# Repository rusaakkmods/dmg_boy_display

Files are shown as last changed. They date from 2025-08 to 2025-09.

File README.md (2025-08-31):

# DMG Boy Display: Real-Time Game Boy LCD Capture System

📋 **[Complete PCB Schematics & BOM Available](schematics/)**

A high-performance Game Boy LCD capture and display system for the Raspberry Pi Pico, supporting multiple TFT display types with hardware-accelerated PIO capture and DMA-optimized rendering.

## 📸 Preview Gallery

| ST7789 (240x240) | ILI9341 (240x320) | ILI9342 (240x320) | ST7796 (320x480) | SH1107 OLED (128x128) |
|:---:|:---:|:---:|:---:|:---:|
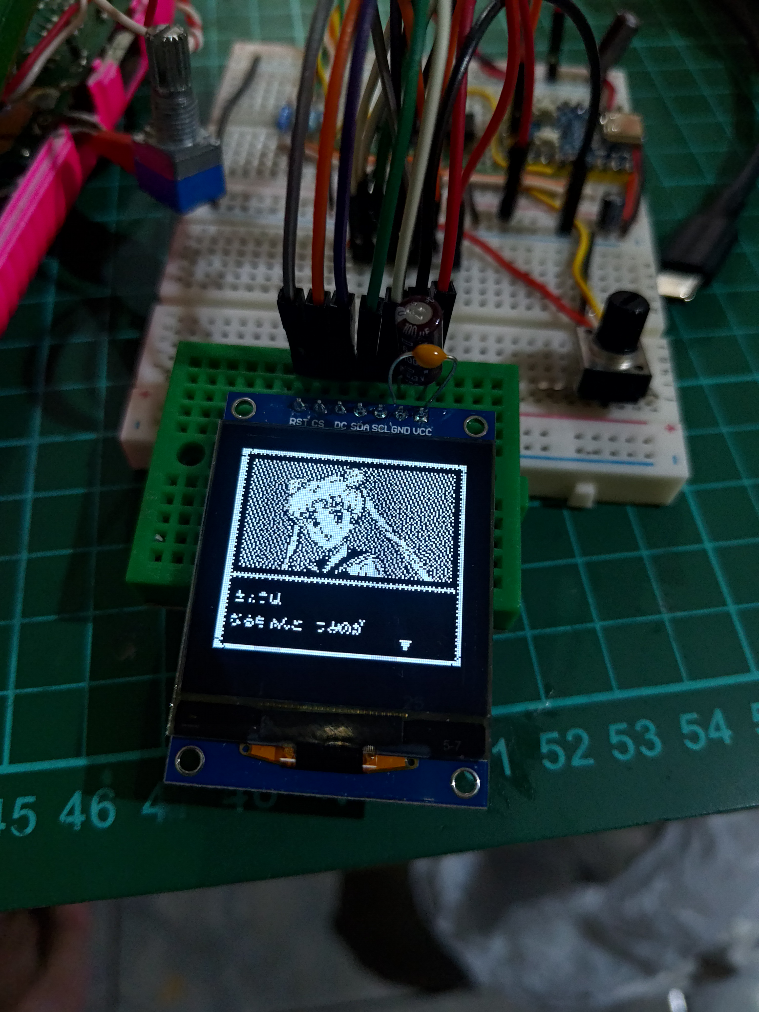
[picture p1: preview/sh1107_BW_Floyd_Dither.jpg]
SH1107
| ST7789 | ILI9341 | ILI9342 | ST7796 |  |
| 1.5x Scaling, Centered | 1.5x Scaling, Top Aligned | 1.5x Scaling, Top Aligned | 2x Scaling, Top Aligned | Floyd-Steinberg Dither, B&W |

| RP2040-Zero Compact | SH1107 OLED Video Demo |
|:---:|:---:|
| RP2040-Zero | SH1107 Video |
| Compact 60% Smaller Build | Monochrome OLED in Action |

📁 **More photos and videos, including new preview images, are available in the [preview/](preview/) folder**

## 📱 Follow My Projects

**🔥 Follow [@rusaakkmods](https://www.instagram.com/rusaakkmods/) on Instagram for more retro gaming mods and electronics projects!**

👍 **Like and follow for:**
- Behind-the-scenes development
- New project updates  
- Retro gaming modifications
- Electronics tutorials

## 🎮 What It Does

This project captures the LCD data from a Game Boy (DMG) in real-time and displays it on modern TFT screens with the following features:

- **Real-Time Capture**: Uses RP2040's PIO (Programmable I/O) for hardware-timed Game Boy LCD signal capture
- **Multi-Display Support**: ST7789, ILI9341, ILI9342, ST7796, and SH1107 OLED displays with optimized drivers
- **Intelligent Scaling**: Automatic resolution scaling with display-specific optimizations
- **Advanced Dithering**: Floyd-Steinberg and Bayer dithering algorithms for monochrome displays
- **DMA Acceleration**: Hardware DMA for fast image transfers and smooth frame rates
- **Color Mapping**: Authentic Game Boy green color palettes for each display type
- **Zero Lag**: Hardware-level capture with minimal latency

## 🖥️ Supported Displays

### ST7789 (240x240)
- **SPI Speed**: 40MHz
- **Scaling**: 1.5x (160x144 → 240x216)
- **Position**: Vertically centered
- **Colors**: Classic Game Boy green tones

### ILI9341 (240x320)
- **SPI Speed**: 40MHz
- **Scaling**: 1.5x (160x144 → 240x216)
- **Position**: Top aligned
- **Colors**: Optimized green palette

### ILI9342 (240x320) *(New!)*
- **SPI Speed**: 40MHz
- **Scaling**: 1.5x (160x144 → 240x216)
- **Position**: Top aligned
- **Colors**: Optimized green palette
- **Notes**: Drop-in replacement for ILI9341 with improved compatibility

### ST7796 (320x480)
- **SPI Speed**: 62.5MHz
- **Scaling**: 2x (160x144 → 320x288)
- **Position**: Top aligned
- **Features**: Enhanced performance optimizations

### SH1107 OLED (128x128) *(New!)*
- **SPI Speed**: 8MHz
- **Resolution**: 128x128 monochrome OLED
- **Scaling**: 0.8x (160x144 → 128x115)
- **Position**: Centered
- **Dithering**: Floyd-Steinberg or Bayer dithering for black & white conversion
- **Features**: Ultra-low power consumption, high contrast ratio

## 🎨 Advanced Dithering Algorithms

### Floyd-Steinberg Dithering *(New!)*
High-quality error diffusion dithering algorithm that provides superior image quality for monochrome displays:
- **Better Quality**: Superior visual results compared to ordered dithering
- **Error Diffusion**: Distributes quantization errors to neighboring pixels
- **Ideal for**: Static images and high-quality monochrome conversion
- **Usage**: Automatically enabled for SH1107 OLED displays

### Bayer Ordered Dithering
Fast, efficient ordered dithering using an 8x8 Bayer matrix:
- **High Performance**: Minimal CPU overhead, perfect for real-time applications
- **Consistent Pattern**: Stable, repeatable dithering pattern
- **Real-time Friendly**: Optimized for continuous Game Boy capture
- **Fallback Option**: Alternative to Floyd-Steinberg when performance is critical

### Black & White (Monochrome) Feature for OLED/Monochrome Displays
For future OLED and other monochrome (1-bit) display support, a new black-and-white mode is available. This mode uses a simple, fast 8x8 Bayer ordered dithering algorithm (instead of the more CPU-intensive Floyd-Steinberg method) to simulate grayscale on black-and-white screens. This approach is chosen for its efficiency and suitability for microcontrollers, making it ideal for OLED and similar displays. Enable this in the display configuration for best results on monochrome hardware.

> **Note:** The Bayer dither is much less CPU-intensive than Floyd-Steinberg, making it a better fit for real-time applications on the RP2040.

## 🔧 Hardware Requirements

### Raspberry Pi Pico
- RP2040 microcontroller
- Standard Pico board or Pico W

### PCB & Components
📋 **[Complete schematics, PCB design, and BOM](schematics/)** available in KiCad format
- Custom PCB recommended for reliable connections
- Through-hole components for easy assembly
- All parts available from common distributors

### Game Boy Connection (DMG-01 Flex Cable)
| Signal | GameBoy LCD Connector | Pico Pin | Description |
|---|---|---|---|
| GND | Pin 21 | GND | Ground |
| Pixel Clock | Pin 14 | GP2 | LCD pixel clock signal |
| Data 0 | Pin 15 | GP3 | LCD data bit 0 |
| Data 1 | Pin 16 | GP4 | LCD data bit 1 |
| Vertical Sync | Pin 12 | GP5 | LCD vertical sync signal |
| Regulated +5V | Pin 11 | VSYS | Power Supply |

### Display Connection (SPI)
| Signal | Pico Pin | Description |
|---|---|---|
| MOSI | GPIO 11  | SPI Data Output |
| SCK | GPIO 10  | SPI Clock |
| CS | GPIO 9 | Chip Select |
| DC | GPIO 12  | Data/Command |
| RESET  | GPIO 13  | Display Reset |
| BL | GPIO 8 | Backlight Control |

## 🚀 Quick Start

### 1. Clone Repository
```bash
git https://github.com/rusaakkmods/dmg_boy_display
cd dmg_boy_display
```

### 2. Configure Display Type
Edit `main.cpp` and uncomment your display type:
```cpp
// Choose display type: uncomment one of these lines
//#define USE_ST7789
//#define USE_ILI9341
//#define USE_ILI9342
//#define USE_ST7796
#define USE_SH1107    // ← Uncomment your display
```

### 3. Build with Ninja (Recommended)
```bash
# Create build directory
mkdir build && cd build

# Configure with Ninja generator (faster builds)
cmake -G Ninja ..

# Build project
ninja

# Flash to Pico
cp dmg_boy_display.uf2 /path/to/pico/drive/
```

### Alternative: Standard Make
```bash
mkdir build && cd build
cmake ..
make -j4
```

## 🏗️ Project Structure

```
├── main.cpp                     # Main application
├── CMakeLists.txt               # Build configuration
├── include/                     # Header files
│   ├── logo.h                  # Logo graphics data
│   ├── dither.hpp              # Dithering algorithms (NEW)
│   ├── scaler.hpp              # Image scaling utilities
│   └── displays/               # Display drivers
│       ├── st7789/            # ST7789 driver
│       ├── ili9341/           # ILI9341 driver
│       ├── ili9342/           # ILI9342 driver
│       ├── ili9488/           # ILI9488 driver (future)
│       ├── sh1107/            # SH1107 OLED driver (NEW)
│       └── st7796/            # ST7796 driver
├── src/                        # Source implementations
│   ├── dither.cpp             # Dithering algorithms (NEW)
│   ├── scaler.cpp             # Image scaling utilities
│   └── displays/              # Driver implementations
│       ├── st7789/            # ST7789 source files
│       ├── ili9341/           # ILI9341 source files
│       ├── ili9342/           # ILI9342 source files
│       ├── ili9488/           # ILI9488 source files
│       ├── sh1107/            # SH1107 OLED source files (NEW)
│       └── st7796/            # ST7796 source files
├── pio/gblcd/                 # PIO programs
│   ├── gblcd.pio             # Game Boy LCD capture
│   └── README.md             # PIO documentation
└── .gitignore                 # Git ignore rules
```

## ⚡ Performance Features

### Hardware Acceleration
- **PIO Capture**: Dedicated state machine for precise Game Boy timing
- **DMA Transfers**: Zero-CPU image copying for smooth frame rates
- **Optimized Scaling**: Pre-computed lookup tables and unrolled loops
- **Advanced Dithering**: Hardware-optimized Floyd-Steinberg and Bayer algorithms

### Display-Specific Optimizations
- **ST7796**: 2x pixel scaling with loop unrolling
- **SH1107 OLED**: Optimized monochrome conversion with dithering
- **Color Lookup**: Pre-computed Game Boy color palettes
- **Buffer Management**: Optimized buffer sizes per display

### Build System
- **Ninja Generator**: Recommended for faster compilation
- **Simplified CMake**: Clean, maintainable build configuration
- **Multi-target**: Single executable with compile-time display selection

## 🔧 Advanced Configuration

### Custom Pin Mapping
Modify pin assignments in `main.cpp`:
```cpp
config.pin_din = 11;    // MOSI
config.pin_sck = 10;    // SCK
config.pin_cs = 9;      // CS
config.pin_dc = 12;     // DC
config.pin_reset = 13;  // RESET
config.pin_bl = 8;      // Backlight
```

### SPI Speed Tuning
Adjust SPI frequencies for your setup:
```cpp
// Conservative (stable)
config.spi_speed_hz = 25 * 1000 * 1000;  // 25MHz

// Aggressive (maximum performance)
config.spi_speed_hz = 62.5 * 1000 * 1000;  // 62.5MHz
```

### DMA Buffer Optimization
Tune buffer sizes for performance:
```cpp
config.dma.buffer_size = 4096;  // Larger = smoother, more RAM
```

### Dithering Algorithm Selection
Choose between dithering algorithms for monochrome displays:
```cpp
// High quality Floyd-Steinberg (slower, better quality)
floyd_steinberg_dither(buffer, width, height, palette, white, black);

// Fast Bayer ordered dithering (faster, good quality)
fast_bayer_dither(buffer, width, height, palette, white, black);
```

## 🐛 Troubleshooting

### Build Issues
```bash
# Clean build
rm -rf build/
mkdir build && cd build
cmake -G Ninja ..
ninja
```

### Display Problems
1. **No Image**: Check SPI connections and power
2. **Wrong Colors**: Verify display type in `main.cpp`
3. **Slow Frame Rate**: Increase SPI speed or enable DMA

### Game Boy Capture Issues
1. **No Signal**: Verify Game Boy LCD connections
2. **Corrupted Image**: Check PIO timing configuration
3. **Sync Problems**: Ensure proper VSync connection

## 📚 Technical Details

### Game Boy LCD Timing
- **Resolution**: 160x144 pixels
- **Refresh Rate**: ~59.7 Hz
- **Color Depth**: 2-bit (4 shades of green)

### Scaling Algorithms
- **1.5x Scaling**: 160→240, 144→216 (ST7789/ILI9341)
- **2x Scaling**: 160→320, 144→288 (ST7796)
- **Nearest Neighbor**: Preserves pixel art aesthetic

### Memory Usage
- **Source Buffer**: 46KB (160x144x2 bytes)
- **Scaled Buffer**: 101KB-180KB (depending on display)
- **SH1107 Buffer**: 2KB (128x128÷8 bytes for monochrome)
- **Dithering Buffer**: 32KB temporary space for Floyd-Steinberg
- **Total RAM**: ~230KB (fits comfortably in RP2040's 264KB)

## 🛠️ Development

### Adding New Displays
1. Create driver files in `include/displays/newdisplay/`
2. Implement source files in `src/displays/newdisplay/`
3. Add display type to `main.cpp`
4. Update `CMakeLists.txt`

### Performance Profiling
Use Pico's built-in profiling:
```cpp
#include "pico/time.h"
absolute_time_t start = get_absolute_time();
// ... your code ...
int64_t elapsed = absolute_time_diff_us(start, get_absolute_time());
```

## 📄 License

This project is open source. See individual files for license information.

## 🤝 Contributing

1. Fork the repository
2. Create a feature branch
3. Test thoroughly on hardware
4. Submit a pull request

## 🙏 Credits

- Thanks to What's Ken Making Youtube Channel, finally I can finish my project. 
  Please follow his Youtube Channel: https://www.youtube.com/@whatskenmaking
- To my kooky AI Claude 4 for assisting me with code optimization, also for it's artificial apologize :D

## 📱 Connect With Me

**Follow [@rusaakkmods](https://www.instagram.com/rusaakkmods/) on Instagram!**

🔥 **Like, follow, and stay updated with:**
- New electronics projects
- Retro gaming modifications  
- Development progress
- Hardware tutorials
- Behind-the-scenes content

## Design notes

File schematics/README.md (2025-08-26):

# DMG Boy Display - Schematic & P### TFT Display Connection (LCD?)
The SPI TFT display connects directly to Raspberry Pi Pico pins:
| Signal | Pico GPIO | Description | Voltage Notes |
|---|---|---|---|
| **VCC** | **3V3/5V** | **Power supply** | **⚠️ See power requirements below** |
| GND | GND | Ground | - |
| CS | GP9 | Chip select | 3.3V logic |
| RESET | GP13 | Display reset | 3.3V logic |
| DC | GP12 | Data/command | 3.3V logic |
| MOSI | GP11 | SPI data | 3.3V logic |
| SCK | GP10 | SPI clock | 3.3V logic |
| BL | GP8 | Backlight control | 3.3V logic |
This folder contains the complete KiCad project files for the DMG Boy Display PCB.

## 📋 Schematic Preview

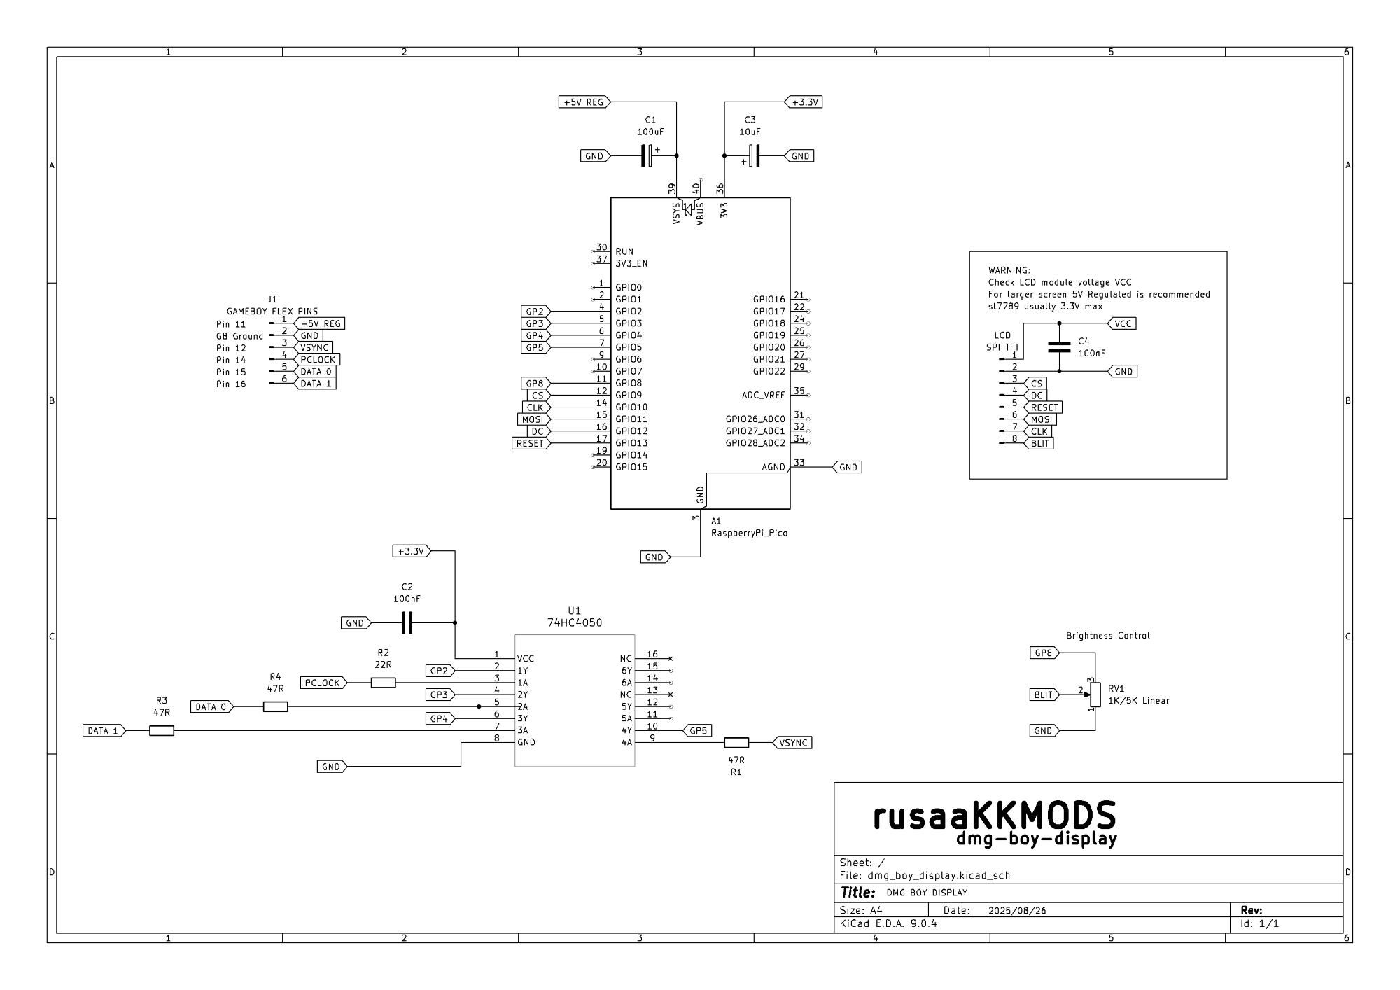
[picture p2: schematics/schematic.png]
Schematic

*Complete schematic showing Game Boy LCD interface and TFT display connections*

## 🛠️ Bill of Materials (BOM)

### Core Components
| Qty | Reference | Value | Package | Description | Datasheet |
|-----|---|---|---|---|---|
| 1 | A1 | RaspberryPi_Pico | THT Module | RP2040 Development Board | [Pico Datasheet](https://datasheets.raspberrypi.com/pico/pico-datasheet.pdf) |
| 1 | U1 | 74HC4050 | N16_TEX | Hex Non-Inverting Buffer | CD74HC4050EG4 |

### Display Interface Components  
| Qty | Reference | Value | Package | Description | Notes |
|-----|---|---|---|---|---|
| 1 | LCD | SPI TFT | Various | TFT Display Module | ST7789/ILI9341/ST7796 |

### Passive Components
| Qty | Reference | Value | Package | Description | Notes |
|-----|---|---|---|---|---|
| 3 | R1,R3,R4 | 47Ω | 0805/THT | Current limiting resistors | Signal conditioning |
| 1 | R2 | 22Ω | 0805/THT | Series resistor | Signal integrity |
| 1 | RV1 | 1K/5K Linear | THT | Potentiometer | Brightness/contrast control |
| 1 | C1 | 100μF | Electrolytic | Power supply capacitor | Bulk decoupling |
| 2 | C2,C4 | 100nF | 0805/THT | Ceramic capacitors | High-freq decoupling |
| 1 | C3 | 10μF | 0805/THT | Tantalum/Ceramic | Power filtering |

### TFT Display Connection (LCD)
The SPI TFT display connects directly to Raspberry Pi Pico pins:
| Signal | Pico GPIO | Description | Voltage Notes |
|---|---|---|---|
| **VCC** | **3V3/5V** | **Power supply** | **⚠️ See power requirements below** |
| GND | GND | Ground | - |
| CS | GP17 | Chip select | 3.3V logic |
| RESET | GP15 | Display reset | 3.3V logic |
| DC | GP20 | Data/command | 3.3V logic |
| MOSI | GP19 | SPI data | 3.3V logic |
| SCK | GP18 | SPI clock | 3.3V logic |
| BL | RV1 Wiper | Backlight control | 3.3V logic |

### ⚠️ Display Power Requirements (VCC)

**IMPORTANT**: Please review your display module's voltage requirements before connecting!

#### Power Options:
1. **3.3V Power (Default/Safe)**
   - Use Pico's 3V3 output
   - ✅ **Safe for all display types**
   - ✅ **ST7789 recommended** (3.3V max)
   - ✅ **Most common configuration**

2. **5V Power (For larger screens)**
   - Use regulated 5V from Game Boy power supply
   - ⚠️ **Check display voltage tolerance first**
   - ✅ **Better for larger displays (3.5"+ screens)**
   - ✅ **Brighter backlight performance**

#### Critical Warnings:
- 🚨 **ST7789 displays**: Usually require **3.3V maximum** - using 5V may damage the display!
- 🚨 **ILI9341 displays**: Check datasheet - some accept 5V, others are 3.3V only
- 🚨 **ST7796 displays**: Most accept 3.3V-5V, but verify your specific module
- 🚨 **Always check your display breakout board specifications**

#### Recommended Approach:
1. **Start with 3.3V** for initial testing (safest option)
2. **Check display performance** - if backlight is too dim for larger screens
3. **Verify 5V compatibility** in your display's datasheet
4. **Only then switch to 5V** if needed and confirmed safe
- **74HC4050 (U1)**: Hex non-inverting buffer for Game Boy signal conditioning
- **RV1 (1K/5K)**: Potentiometer for brightness/contrast adjustment
- **R1,R3,R4 (47Ω)**: Current limiting resistors for signal integrity
- **R2 (22Ω)**: Series resistor for signal conditioning
- **C1 (100μF)**: Bulk power supply decoupling
- **C2,C4 (100nF)**: High-frequency noise filtering
- **C3 (10μF)**: Additional power supply filtering

## 🔍 Design Validation

### Signal Integrity
✅ Proper impedance control for SPI signals  
✅ Adequate ground plane coverage  
✅ Decoupling capacitors near power pins  
✅ Short trace lengths for high-speed signals  

### Power Integrity  
✅ Dedicated power planes  
✅ Power supply filtering  
✅ Current capacity analysis  
✅ Thermal considerations  

## 📧 Support

For questions about the PCB design:
- 📱 Follow [@rusaakkmods](https://www.instagram.com/rusaakkmods/) on Instagram
- 🐛 Open an issue in this repository
- 💬 Discussion in project README

---

**PCB Design by [@rusaakkmods](https://www.instagram.com/rusaakkmods/)**

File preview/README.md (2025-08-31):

# DMG Boy Display - Preview Gallery

This folder contains preview images and videos of the DMG Boy Display project in action with different TFT displays.

## 📸 Preview Images

### ST7789 Display (240x240)
ST7789 Display
*ST7789 240x240 display showing Game Boy content with 1.5x scaling*

### ILI9341 Display (240x320)
ILI9341 Display
*ILI9341 240x320 display showing Game Boy content with 1.5x scaling*

### ILI9342 Display (240x320) *(New!)*
ILI9342 Display
*ILI9342 240x320 display showing Game Boy content with 1.5x scaling*

### ST7796 Display (320x480)
ST7796 Display
*ST7796 320x480 display showing Game Boy content with 2x scaling*

### SH1107 OLED Display (128x128) *(New!)*
SH1107 OLED
*SH1107 128x128 monochrome OLED display with Floyd-Steinberg dithering*

### RP2040-Zero Compact Build
RP2040-Zero Build
*Compact build using Waveshare RP2040-Zero for minimal footprint*

## 🎥 Video Demo
- `preview.mp4` - Video demonstration of the system in action
- `rp2040-Zero_preview.mp4` - RP2040-Zero compact build demonstration
- `sh1107_Monochroe_OLED.mp4` - SH1107 OLED display with real-time dithering *(New!)*

## 📱 Follow for More Projects

**Follow me on Instagram for more retro gaming mods and electronics projects:**

**[@rusaakkmods](https://www.instagram.com/rusaakkmods/)**

🔥 Don't forget to **like** and **follow** for:
- Behind-the-scenes development
- New project updates
- Retro gaming modifications
- Electronics tutorials
- Hardware hacks

## 🛠️ Hardware Specifications

All images show the same Game Boy LCD capture system with different configurations:

### Standard Pico Build
- **Raspberry Pi Pico** (RP2040)
- **Real-time PIO capture** from Game Boy DMG-01
- **Hardware DMA acceleration** for smooth frame rates
- **Authentic Game Boy color palettes**

### Compact RP2040-Zero Build  
- **Waveshare RP2040-Zero** (23.5×18mm)
- **60% smaller** than standard Pico
- **Same performance** and capabilities
- **Ideal for portable/embedded applications**

## 📐 Display Comparisons

| Display  | Resolution | Scaling | Position | Performance | Type |
|---|---|---|---|---|---|
| ST7789 | 240x240 | 1.5x | Centered | 40MHz SPI | TFT Color |
| ILI9341  | 240x320 | 1.5x | Top | 40MHz SPI | TFT Color |
| ILI9342  | 240x320 | 1.5x | Top | 40MHz SPI | TFT Color |
| ST7796 | 320x480 | 2.0x | Top | 62.5MHz SPI | TFT Color |
| SH1107 | 128x128 | 0.8x | Centered | 40MHz SPI | OLED Mono |

## 🎨 Dithering Algorithms *(New!)*

The SH1107 OLED display showcases two advanced dithering algorithms for black & white conversion:

### Floyd-Steinberg Dithering *(Featured in Preview)*
- **High Quality**: Superior visual results with error diffusion
- **Better Detail**: Preserves fine details and gradients
- **Shown in Images**: The preview images demonstrate Floyd-Steinberg quality
- **Best for**: High-quality static conversion and detailed images

### Bayer Ordered Dithering *(Alternative)*
- **High Performance**: Minimal CPU overhead for real-time use
- **Consistent Pattern**: Stable, repeatable results
- **Real-time Friendly**: Optimized for continuous Game Boy capture
- **Best for**: Real-time applications where speed is critical

---

## Black & White (Monochrome) Feature for OLED/Monochrome Displays

A new black-and-white mode is now available for future OLED and other monochrome (1-bit) display support. This mode uses a simple, fast 8x8 Bayer ordered dithering algorithm (instead of the more CPU-intensive Floyd-Steinberg method) to simulate grayscale on black-and-white screens. This approach is chosen for its efficiency and suitability for microcontrollers, making it ideal for OLED and similar displays. Enable this in the display configuration for best results on monochrome hardware.

> **Note:** The Bayer dither is much less CPU-intensive than Floyd-Steinberg, making it a better fit for real-time applications on the RP2040.

---

**Project by [@rusaakkmods](https://www.instagram.com/rusaakkmods/)**

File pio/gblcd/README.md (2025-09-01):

# Game Boy LCD Capture (gblcd.pio)

A high-performance PIO (Programmable I/O) program for capturing Game Boy LCD data using the Raspberry Pi Pico.

## Author

**Ken (What's Ken Making)**
- GitHub: [@whatskenmaking](https://github.com/whatskenmaking)
- YouTube: [What's Ken Making](https://www.youtube.com/@whatskenmaking)
- Master Repository: [Pico-DMG-LCD](https://github.com/whatskenmaking/Pico-DMG-LCD)

## Overview

The `gblcd.pio` is a specialized PIO program designed to capture raw LCD data from the original Game Boy (DMG) hardware in real-time. This library enables the Raspberry Pi Pico to act as a high-speed data capture interface between the Game Boy's LCD controller and external display devices.

## What it Does

The gblcd.pio program captures:
- **Pixel Data**: Raw 2-bit grayscale pixel information from the Game Boy LCD
- **Timing Signals**: VSYNC and pixel clock synchronization
- **Frame Data**: Complete 160x144 pixel frames at 59.7 Hz refresh rate
- **Real-time Processing**: Zero-latency capture suitable for live display output

## How it Works

### PIO Architecture
The program utilizes the RP2040's Programmable I/O (PIO) **Single State Machine** to captures pixel data and VSYNC with precise clock synchronization
   - Waits for clock edges on PIO pin index 0 (GPIO 2 - Game Boy clock)
   - Reads 4 input pins simultaneously using pin indices 0-3 (GPIO 2-5)
   - PIO pin index 0 (GPIO 2): Game Boy clock signal (CPG)
   - PIO pin index 1 (GPIO 3): Pixel data bit 0 (LD0)
   - PIO pin index 2 (GPIO 4): Pixel data bit 1 (LD1)
   - PIO pin index 3 (GPIO 5): VSYNC signal
   - Transfers data to main CPU via FIFO

### Signal Capture Process

```
Game Boy LCD → PIO State Machine → CPU Processing → External Display
```

#### 1. Signal Input
- **CPG (Clock Pulse Generator)**: 4.194304 MHz pixel clock from Game Boy (GPIO 2)
- **LD0-LD1**: 2-bit pixel data lines (grayscale values 0-3) on GPIO 3-4
- **VSYNC**: Vertical sync signal for frame timing (GPIO 5)
- Note: PIO waits on clock (GPIO 2) then captures all signals simultaneously

#### 2. Data Processing
- PIO captures 2-bit pixels at 4.194304 MHz rate
- Each line contains 160 pixels (320 bits of data)
- Frame consists of 144 active lines
- Automatic synchronization with Game Boy timing using VSYNC

#### 3. Memory Management
- CPU polling of PIO FIFO for continuous capture
- 23,040 bytes per frame (160×144×1 byte per pixel)
- Frame synchronization via VSYNC detection
- Direct transfer to display drivers

### Technical Specifications

| Parameter | Value |
|---|---|
| Input Clock | 4.194304 MHz |
| Frame Rate | ~59.7 Hz |
| Resolution | 160×144 pixels |
| Color Depth | 2-bit grayscale (4 shades) |
| Data Rate | ~1.97 MB/s |
| Latency | <1 frame (~16.7ms) |

## Usage

### Hardware Connections
Connect the following Game Boy signals to Raspberry Pi Pico GPIO pins:

```cpp
// Pin assignments - PIO uses pin indices starting from GPIO 2
#define GB_CLK_PIN    2   // Game Boy pixel clock (CPG) - PIO pin index 0
#define GB_DATA0_PIN  3   // Game Boy data bit 0 (LD0) - PIO pin index 1
#define GB_DATA1_PIN  4   // Game Boy data bit 1 (LD1) - PIO pin index 2  
#define GB_VSYNC_PIN  5   // Game Boy vertical sync (VSYNC) - PIO pin index 3

// PIO configuration maps pin indices to GPIO pins:
// sm_config_set_in_pins(&config, 2) sets GPIO 2 as PIO pin index 0
// This automatically assigns GPIO 3,4,5 to PIO pin indices 1,2,3
```

### Software Integration

The PIO program is automatically compiled and included in your project:

```cpp
#include "gblcd.pio.h"

// Initialize PIO program
uint offset = pio_add_program(pio0, &gblcd_program);
gblcd_program_init(pio0, 0, offset, clk_pin, data_pin);
```

## Performance Features

- **Minimal CPU Overhead**: PIO handles timing-critical pixel capture
- **FIFO Integration**: Automatic data transfers without complex buffering
- **Real-time Capture**: Frame-synchronized capture via VSYNC detection
- **Low Latency**: Immediate processing suitable for gaming applications
- **Power Efficient**: Dedicated hardware reduces power consumption

## Applications

This library enables various Game Boy LCD capture applications:
- External display drivers (ST7789, ILI9341, ST7796)
- LCD replacement/upgrade projects
- Game Boy video recording systems
- Real-time streaming solutions
- Emulator development and testing

## Technical Notes

### Timing Requirements
- The PIO program is carefully tuned for Game Boy LCD timing
- Clock edges and data sampling are precisely aligned
- VSYNC detection ensures proper frame synchronization

### Buffer Management
- Implements ping-pong buffering for continuous operation
- Automatic detection of frame boundaries
- Configurable buffer sizes for different display types

### Compatibility
- Designed for original Game Boy (DMG) hardware
- Compatible with Game Boy Color in DMG mode
- Supports various Game Boy LCD revisions

## License

This project is part of the Pico-DMG-LCD repository. Please refer to the main repository for licensing information.

## Contributing

For questions, issues, or contributions:
1. Visit the [main repository](https://github.com/whatskenmaking/Pico-DMG-LCD)
2. Check out the [YouTube channel](https://www.youtube.com/@whatskenmaking) for tutorials
3. Submit issues or pull requests on GitHub

---

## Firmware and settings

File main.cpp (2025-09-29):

#include <stdio.h>
#include <stdlib.h>
#include <string.h>
#include "pico/stdlib.h"
#include "logo.h"
#include "scaler.hpp"
#include "dither.hpp"
#include "palettes.hpp"
#include <stdbool.h>
#include "hardware/pio.h"
#include "hardware/spi.h"
#include "gblcd.pio.h"

// Choose display type: uncomment one of these lines
//#define USE_ST7789
#define USE_ILI9341
//#define USE_ILI9342
//#define USE_ST7796
//#define USE_SH1107

// Uncomment to enable dithering for monochrome display
//#define ENABLE_BW_DITHER

// Dithering quality options (choose one if ENABLE_BW_DITHER is defined):
// DITHER_FAST - Original Bayer dithering (fastest)
// DITHER_BEST - Floyd-Steinberg error diffusion (best quality, higher performance cost)
#define DITHER_BEST

// Palette selection
#define SELECTED_PALETTE PALETTE_MODERN2

//#define ENABLE_ST7789_NEGATIVE_FILM

// Force BW dither for SH1107 monochrome display
#if defined(USE_SH1107)
    #ifndef ENABLE_BW_DITHER
        #define ENABLE_BW_DITHER
    #endif
#endif

// Pin definitions
#define SPI_CHANNEL spi1
#define PIN_MOSI 11
#define PIN_SCK 10
#define PIN_CS 9
#define PIN_DC 12
#define PIN_RESET 13
#define PIN_BL 8

#define DMG_W 160
#define DMG_H 144

#ifdef USE_ST7789
    #include "displays/st7789/st7789.hpp"
    #ifdef ENABLE_ST7789_NEGATIVE_FILM
        #define LCD_W 320
        #define LCD_H 240
        #define Y_OFF 0
        #define X_OFF 26
        #define DISPLAY_ROTATION st7789::ROTATION_270
        #define FILL_COLOR st7789::WHITE
        #define DISPLAY_SCALE 1.67
    #else
        #define LCD_W 240
        #define LCD_H 240
        #define Y_OFF 12
        #define X_OFF 0
        #define DISPLAY_ROTATION st7789::ROTATION_0
        #define FILL_COLOR st7789::BLACK
        #define DISPLAY_SCALE 1.5
    #endif
#elif defined(USE_ILI9341)
    #include "displays/ili9341/ili9341.hpp"
    #define LCD_W 320      
    #define LCD_H 240      
    #define Y_OFF 7
    #define X_OFF 46   
    #define DISPLAY_ROTATION ili9341::ROTATION_270
    #define FILL_COLOR ili9341::BLACK
    #define DISPLAY_SCALE 1.6
#elif defined(USE_ILI9342)
    #include "displays/ili9342/ili9342.hpp"
    #define LCD_W 320
    #define LCD_H 240
    #define Y_OFF 12
    #define X_OFF 40
    #define DISPLAY_ROTATION ili9342::ROTATION_0
    #define FILL_COLOR ili9342::BLACK
    #define DISPLAY_SCALE 1.5
#elif defined(USE_ST7796)
    #include "displays/st7796/st7796.hpp"
    #define LCD_W 320
    #define LCD_H 480
    #define Y_OFF 0 
    #define X_OFF 0
    #define DISPLAY_ROTATION st7796::ROTATION_180
    #define FILL_COLOR st7796::BLACK
    #define DISPLAY_SCALE 2
#elif defined(USE_SH1107)
    #include "displays/sh1107/sh1107.hpp"
    #define LCD_W 128
    #define LCD_H 128
    #define Y_OFF 6
    #define X_OFF 0
    #define DISPLAY_ROTATION sh1107::ROTATION_180
    #define FILL_COLOR sh1107::BLACK
    #define DISPLAY_SCALE 0.8
#else
    #error "Please define a display type"
#endif

#define SCALED_W (int)(DMG_W * DISPLAY_SCALE + 0.5f)
#define SCALED_H (int)(DMG_H * DISPLAY_SCALE + 0.5f)

static const uint16_t BW_BLACK = 0x0000;
static const uint16_t BW_WHITE = 0xFFFF;

// Palettes setup
#ifdef ENABLE_BW_DITHER
    #ifdef DITHER_BEST
        static const uint16_t gb_colors[4] = {
            0xFFFF, 0xAAAA, 0x4444, 0x0000
        };
    #else
        static const uint16_t gb_colors[4] = {
            0xFFFF, 0x9999, 0x5555, 0x0000
        };
    #endif
#else
    static const uint16_t* gb_colors = SELECTED_PALETTE;
#endif

int main() {
    stdio_init_all();
    
#ifdef USE_ST7789
    st7789::ST7789 lcd;
    st7789::Config config;
    config.spi_speed_hz = 40 * 1000 * 1000;
    config.dma.buffer_size = 480;
    config.dma.enabled = true;
#elif defined(USE_ILI9341)
    ili9341::ILI9341 lcd;
    ili9341::Config config;
    config.spi_speed_hz = 40 * 1000 * 1000;
    config.dma.buffer_size = 2560;
    config.dma.enabled = true;
#elif defined(USE_ILI9342)
    ili9342::ILI9342 lcd;
    ili9342::Config config;
    config.spi_speed_hz = 40 * 1000 * 1000;
    config.dma.buffer_size = 960;
    config.dma.enabled = true;
#elif defined(USE_ST7796)
    st7796::ST7796 lcd;
    st7796::Config config;
    config.spi_speed_hz = 62.5 * 1000 * 1000;
    config.dma.buffer_size = 4096;
    config.dma.enabled = true;
#elif defined(USE_SH1107)
    sh1107::SH1107 lcd;
    sh1107::Config config;
    config.spi_speed_hz = 8 * 1000 * 1000;
    config.dma.enabled = true;
    config.dma.buffer_size = 256;
#endif

    // Set common config values
    config.width = LCD_W;
    config.spi_inst = SPI_CHANNEL;
    config.pin_din = PIN_MOSI;
    config.pin_sck = PIN_SCK;
    config.pin_cs = PIN_CS;
    config.pin_dc = PIN_DC;
    config.pin_reset = PIN_RESET;
    config.pin_bl = PIN_BL;
    config.rotation = DISPLAY_ROTATION;
    
    lcd.begin(config);
    lcd.setRotation(config.rotation);

#if defined(USE_SH1107)
    lcd.setBrightness(64);
#elif defined(USE_ILI9341)
    lcd.setBrightness(255);
#endif

    lcd.clearScreen(RMODS_LOGO_BACKGROUND);
    
#ifdef ENABLE_TEST_COLOR
    // Test color rendering to verify display driver works
    uint16_t test_red = 0xF800;    // Pure red in RGB565
    uint16_t test_green = 0x07E0;  // Pure green in RGB565  
    uint16_t test_blue = 0x001F;   // Pure blue in RGB565
    uint16_t test_yellow = 0xFFE0; // Pure yellow in RGB565
    
    // Draw test color bars - these should show correct colors
    lcd.fillRect(0, 0, 80, 60, test_red);
    lcd.fillRect(80, 0, 80, 60, test_green);  
    lcd.fillRect(160, 0, 80, 60, test_blue);
    lcd.fillRect(240, 0, 80, 60, test_yellow);
    
    // Test our Game Boy palette colors directly
    lcd.fillRect(0, 60, 80, 60, gb_colors[0]);   // Should be yellow/cream
    lcd.fillRect(80, 60, 80, 60, gb_colors[1]);  // Should be brown
    lcd.fillRect(160, 60, 80, 60, gb_colors[2]); // Should be dark brown  
    lcd.fillRect(240, 60, 80, 60, gb_colors[3]); // Should be very dark
    
    sleep_ms(3000); // Wait 3 seconds to see test colors
#endif

    #ifdef ENABLE_BW_DITHER
        static const uint16_t* logo = (uint16_t*)rMODS_logo_bw_smaller;
        int logo_width = SMALLER_LOGO_WIDTH;
        int logo_height = SMALLER_LOGO_HEIGHT;
    #else
        static const uint16_t* logo = (uint16_t*)rMODS_logo_data;
        int logo_width = RMODS_LOGO_WIDTH;
        int logo_height = RMODS_LOGO_HEIGHT;
    #endif
    int logo_x = (int)(X_OFF + (SCALED_W - logo_width) / 2);
    int logo_y = (int)(Y_OFF + (SCALED_H - logo_height) / 2);
    lcd.drawImage(logo_x, logo_y, logo_width, logo_height, logo);
    sleep_ms(1000);

    // PIO setup
    PIO pio = pio0; // gblcd.pio
    uint state_machine_id = 0;
    uint offset = pio_add_program(pio, &gblcd_program);
    gblcd_program_init(pio, state_machine_id, offset);

    int x = 0, y = 0;
    bool vSyncPrev = false;
    bool vSyncCurrent = false;
    bool vSyncFallingEdgeDetected = false;
    bool firstRun = false;

    static uint16_t screenBuffer[DMG_W * DMG_H];
    static uint16_t scaledBuf[SCALED_W * SCALED_H];
    uint16_t data0, data1, vSync;

    static int xmap[SCALED_W];
    static int ymap[SCALED_H];
    buildScaleMaps(xmap, ymap, DMG_W, DMG_H, SCALED_W, SCALED_H, DISPLAY_SCALE);

    while (true) {
        uint32_t result = pio_sm_get_blocking(pio, state_machine_id);
        vSync = (result >> 31) & 1;

        vSyncCurrent = vSync;
        vSyncFallingEdgeDetected = (!vSyncCurrent && vSyncPrev);
        vSyncPrev = vSyncCurrent;

        if (!vSyncFallingEdgeDetected) {
            continue;
        }

        if (!firstRun) {
            firstRun = true;
            lcd.clearScreen(FILL_COLOR);
        }

        // ---- Capture 160x144 into screenBuffer ----
        uint16_t* bufPtr = screenBuffer;
        
        for (y = 0; y < DMG_H; y++) {
            for (x = 0; x < DMG_W; x++) {
                if (x > 0 || y > 0) result = pio_sm_get_blocking(pio, state_machine_id);
                
                // Extract Game Boy LCD data bits
                data0 = (result >> 29) & 1;  // LD0 - GPIO 3
                data1 = (result >> 30) & 1;  // LD1 - GPIO 4
                
                // Game Boy pixel format: LD1,LD0 forms 2-bit value (0-3)
                uint8_t gb_pixel_value = (data1 << 1) | data0;
                
                *bufPtr++ = gb_colors[gb_pixel_value];
            }
        }

        if (DISPLAY_SCALE == 1) {
            memcpy(scaledBuf, screenBuffer, DMG_W * DMG_H * sizeof(uint16_t));
        }
        else {
            for (int dy = 0; dy < SCALED_H; dy++) {
                const uint16_t* srcRow = &screenBuffer[ ymap[dy] * DMG_W ];
                uint16_t* dstRow = &scaledBuf[ dy * SCALED_W ];
                int dx = 0;
                for (; dx <= SCALED_W - 8; dx += 8) {
                    dstRow[dx] = srcRow[xmap[dx]];
                    dstRow[dx + 1] = srcRow[xmap[dx + 1]];
                    dstRow[dx + 2] = srcRow[xmap[dx + 2]];
                    dstRow[dx + 3] = srcRow[xmap[dx + 3]];
                    dstRow[dx + 4] = srcRow[xmap[dx + 4]];
                    dstRow[dx + 5] = srcRow[xmap[dx + 5]];
                    dstRow[dx + 6] = srcRow[xmap[dx + 6]];
                    dstRow[dx + 7] = srcRow[xmap[dx + 7]];
                }
                for (; dx < SCALED_W; dx++) {
                    dstRow[dx] = srcRow[xmap[dx]];
                }
            }
        }
        
#ifdef ENABLE_BW_DITHER
    #if defined(DITHER_BEST)
        floyd_steinberg_dither(scaledBuf, SCALED_W, SCALED_H, gb_colors, BW_WHITE, BW_BLACK);
    #else
        fast_bayer_dither(scaledBuf, SCALED_W, SCALED_H, gb_colors, BW_WHITE, BW_BLACK);
    #endif
#endif

        lcd.drawImage(X_OFF, Y_OFF, SCALED_W, SCALED_H, scaledBuf);
        vSyncFallingEdgeDetected = false;
    }
    return 0;
}

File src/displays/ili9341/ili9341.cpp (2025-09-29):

#include "displays/ili9341/ili9341.hpp"
#include <cstdio>

namespace ili9341 {

// ILI9341 command definitions
enum ILI9341_CMD {
    ILI9341_NOP         = 0x00,
    ILI9341_SWRESET     = 0x01,
    ILI9341_RDDID       = 0x04,
    ILI9341_RDDST       = 0x09,
    ILI9341_SLPIN       = 0x10,
    ILI9341_SLPOUT      = 0x11,
    ILI9341_PTLON       = 0x12,
    ILI9341_NORON       = 0x13,
    ILI9341_RDMODE      = 0x0A,
    ILI9341_RDMADCTL    = 0x0B,
    ILI9341_RDPIXFMT    = 0x0C,
    ILI9341_RDIMGFMT    = 0x0D,
    ILI9341_RDSELFDIAG  = 0x0F,
    ILI9341_INVOFF      = 0x20,
    ILI9341_INVON       = 0x21,
    ILI9341_GAMMASET    = 0x26,
    ILI9341_DISPOFF     = 0x28,
    ILI9341_DISPON      = 0x29,
    ILI9341_CASET       = 0x2A,
    ILI9341_PASET       = 0x2B,
    ILI9341_RAMWR       = 0x2C,
    ILI9341_RAMRD       = 0x2E,
    ILI9341_PTLAR       = 0x30,
    ILI9341_MADCTL      = 0x36,
    ILI9341_VSCRSADD    = 0x37,
    ILI9341_PIXFMT      = 0x3A,
    ILI9341_FRMCTR1     = 0xB1,
    ILI9341_FRMCTR2     = 0xB2,
    ILI9341_FRMCTR3     = 0xB3,
    ILI9341_INVCTR      = 0xB4,
    ILI9341_DFUNCTR     = 0xB6,
    ILI9341_PWCTR1      = 0xC0,
    ILI9341_PWCTR2      = 0xC1,
    ILI9341_PWCTR3      = 0xC2,
    ILI9341_PWCTR4      = 0xC3,
    ILI9341_PWCTR5      = 0xC4,
    ILI9341_VMCTR1      = 0xC5,
    ILI9341_VMCTR2      = 0xC7,
    ILI9341_GMCTRP1     = 0xE0,
    ILI9341_GMCTRN1     = 0xE1,
    ILI9341_PWCTR6      = 0xFC
};

// MADCTL parameter bit definitions
#define MADCTL_MY  0x80  // Bottom to top
#define MADCTL_MX  0x40  // Right to left
#define MADCTL_MV  0x20  // Reverse Mode
#define MADCTL_ML  0x10  // LCD refresh Bottom to top
#define MADCTL_RGB 0x00  // Red-Green-Blue pixel order
#define MADCTL_BGR 0x08  // Blue-Green-Red pixel order
#define MADCTL_MH  0x04  // LCD refresh right to left

ILI9341::ILI9341() : _gfx(this), _initialized(false) {
}

ILI9341::~ILI9341() {
}

bool ILI9341::begin(const Config& config) {
    if (_initialized) {
        return true;
    }
    
    // Convert to native config format
    Config native_config = config;
    
    // Initialize hardware abstraction layer
    if (!_hal.init(native_config)) {
        printf("Failed to initialize ILI9341 hardware abstraction layer\n");
        return false;
    }
    
    // Initialize display
    initializeDisplay();
    
    _initialized = true;
    return true;
}

bool ILI9341::begin(spi_inst_t* spi, uint8_t cs_pin, uint8_t dc_pin, 
                   uint8_t rst_pin, uint8_t bl_pin,
                   uint16_t width, uint16_t height) {
    Config config;
    config.spi_inst = spi;
    config.pin_cs = cs_pin;
    config.pin_dc = dc_pin;
    config.pin_reset = rst_pin;
    config.pin_bl = bl_pin;
    config.width = width;
    config.height = height;
    
    return begin(config);
}

void ILI9341::initializeDisplay() {
    // Hardware reset
    _hal.reset();
    
    // Software reset
    _hal.writeCommand(ILI9341_SWRESET);
    _hal.delay(150);
    
    // Exit sleep mode
    _hal.writeCommand(ILI9341_SLPOUT);
    _hal.delay(120);
    
    // Power control A
    _hal.writeCommand(0xCB);
    _hal.writeData(0x39);
    _hal.writeData(0x2C);
    _hal.writeData(0x00);
    _hal.writeData(0x34);
    _hal.writeData(0x02);
    
    // Power control B
    _hal.writeCommand(0xCF);
    _hal.writeData(0x00);
    _hal.writeData(0xC1);
    _hal.writeData(0x30);
    
    // Driver timing control A
    _hal.writeCommand(0xE8);
    _hal.writeData(0x85);
    _hal.writeData(0x00);
    _hal.writeData(0x78);
    
    // Driver timing control B
    _hal.writeCommand(0xEA);
    _hal.writeData(0x00);
    _hal.writeData(0x00);
    
    // Power on sequence control
    _hal.writeCommand(0xED);
    _hal.writeData(0x64);
    _hal.writeData(0x03);
    _hal.writeData(0x12);
    _hal.writeData(0x81);
    
    // Pump ratio control
    _hal.writeCommand(0xF7);
    _hal.writeData(0x20);
    
    // Power control 1
    _hal.writeCommand(ILI9341_PWCTR1);
    _hal.writeData(0x23);
    
    // Power control 2
    _hal.writeCommand(ILI9341_PWCTR2);
    _hal.writeData(0x10);
    
    // VCOM control 1
    _hal.writeCommand(ILI9341_VMCTR1);
    _hal.writeData(0x3e);
    _hal.writeData(0x28);
    
    // VCOM control 2
    _hal.writeCommand(ILI9341_VMCTR2);
    _hal.writeData(0x86);
    
    // Memory access control (BGR format for color correction)
    _hal.writeCommand(ILI9341_MADCTL);
    _hal.writeData(0x48);  // MX=1, BGR order to fix color channel swap
    
    // Pixel format
    _hal.writeCommand(ILI9341_PIXFMT);
    _hal.writeData(0x55);  // 16 bits/pixel
    
    // Frame rate control
    _hal.writeCommand(ILI9341_FRMCTR1);
    _hal.writeData(0x00);
    _hal.writeData(0x18);
    
    // Display function control
    _hal.writeCommand(ILI9341_DFUNCTR);
    _hal.writeData(0x08);
    _hal.writeData(0x82);
    _hal.writeData(0x27);
    
    // Gamma function disable
    _hal.writeCommand(0xF2);
    _hal.writeData(0x00);
    
    // Gamma curve selection
    _hal.writeCommand(ILI9341_GAMMASET);
    _hal.writeData(0x01);
    
    // Positive gamma control
    _hal.writeCommand(ILI9341_GMCTRP1);
    _hal.writeData(0x0F);
    _hal.writeData(0x31);
    _hal.writeData(0x2B);
    _hal.writeData(0x0C);
    _hal.writeData(0x0E);
    _hal.writeData(0x08);
    _hal.writeData(0x4E);
    _hal.writeData(0xF1);
    _hal.writeData(0x37);
    _hal.writeData(0x07);
    _hal.writeData(0x10);
    _hal.writeData(0x03);
    _hal.writeData(0x0E);
    _hal.writeData(0x09);
    _hal.writeData(0x00);
    
    // Negative gamma control
    _hal.writeCommand(ILI9341_GMCTRN1);
    _hal.writeData(0x00);
    _hal.writeData(0x0E);
    _hal.writeData(0x14);
    _hal.writeData(0x03);
    _hal.writeData(0x11);
    _hal.writeData(0x07);
    _hal.writeData(0x31);
    _hal.writeData(0xC1);
    _hal.writeData(0x48);
    _hal.writeData(0x08);
    _hal.writeData(0x0F);
    _hal.writeData(0x0C);
    _hal.writeData(0x31);
    _hal.writeData(0x36);
    _hal.writeData(0x0F);
    
    // Exit sleep mode
    _hal.writeCommand(ILI9341_SLPOUT);
    _hal.delay(120);
    
    // Display on
    _hal.writeCommand(ILI9341_DISPON);
    _hal.delay(120);
    
    // Set display orientation
    setRotation(_hal.getConfig().rotation);
    
    // Set memory window to full screen
    setAddrWindow(0, 0, _hal.getConfig().width - 1, _hal.getConfig().height - 1);
    
    // Clear screen to black
    fillScreen(BLACK);
    
    // Turn on backlight
    setBacklight(true);
}
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

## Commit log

2025-08-26 change pinout for convinient and portabilty
    [dmg_boy_display.kicad_sch]
2025-08-31 fix no dma for sh1107
    [main.cpp]
2025-08-31 tweak spi speed to 16 for sh1107.
2025-08-31 sh1107 stable for 3.3v but with low brightness
2025-08-31 sh1107 fix power by reduing brightness.. although theres is elegant way for power management using sm1117. not too ambitious about this display
    [main.cpp]
2025-09-12 kicad updated
2025-09-29 fix ili9341 color renderign
    [ili9341.cpp, ili9341_hal.cpp, main.cpp]
2025-09-29 correct color rendering for ili9341
    [main.cpp]
